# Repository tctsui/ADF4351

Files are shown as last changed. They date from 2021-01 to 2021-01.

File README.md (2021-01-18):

# ADF4351 Wideband RF Synthesizer

## Introduction
This porject is designed to incorporate Analog Devices ADF 4351 chip with Teensy 3.6. On the bottom right corner, there are two slots reserved for two different TCXO oscillators 535L250X2GT5 and XNCLH25M000THJA0P0. Only one of them should be used. The ADF4351 can be controlled using SPI by the Teensy 3.6 on-board or externally using the header pin when the Teensy is unplugged. The Teensy 3.6 is also powered by this board, so please cut the 5V pad according to https://www.pjrc.com/teensy/external_power.html  before use. The library used to control the ADF4351 chip is mostly based on the code written by David Fannin (dfannin). The register writing part of this code is adapted from the code written by Neal Pisenti (npisenti). The library is still under development, so use it with cautions.

## Hardware
### TXCO oscillators
This PCB is designed such that either 535L250X2GT5 or XNCLH25M000THJA0P0 can be used. If oscillator with frequency other than 25MHz, a corresponding modifcation to the SPI control library has to be made.
### Fast Lock Loop Filter Topology
In order to increase the lock speed, the board is modified according to page 23 in the ADF4351 manual.(a 0 Ohm on R5 and replace R4 with a 1k Ohm resistor). The SPI control library in this repository is also adapted to work under the fast lock.

### Teensy 3.6
The Teensy 3.6 is designed to be directly power by the board, so please cut the 5V pad according to https://www.pjrc.com/teensy/external_power.html  before use.

## Software
Most of code in the .cpp is based on the code written by David Fannin (dfannin). The register writing part of the code is adapted from the code written by Neal Pisenti (npisenti). 
I modidified the code to enable the fast lock functionality and calculate the different parameters required for the fast lock operation. Moreover, I added a new function FastScanSetF which only updates one register when call instead of 6. Before using FastScanSetF, FastscanabilityCheckhas to be called to set the remaining 5 registers.

## References

+ [ADF4351 Product Page](https://goo.gl/tkMjw6) Analog Devices
+ [SV1AFN ADF4351 Board](https://www.sv1afn.com/adf4351m.html) by Makis Katsouris, SV1AFN
+ [Big Number Arduino Library](https://github.com/nickgammon/BigNumber) by Nick Gammon

## Picture


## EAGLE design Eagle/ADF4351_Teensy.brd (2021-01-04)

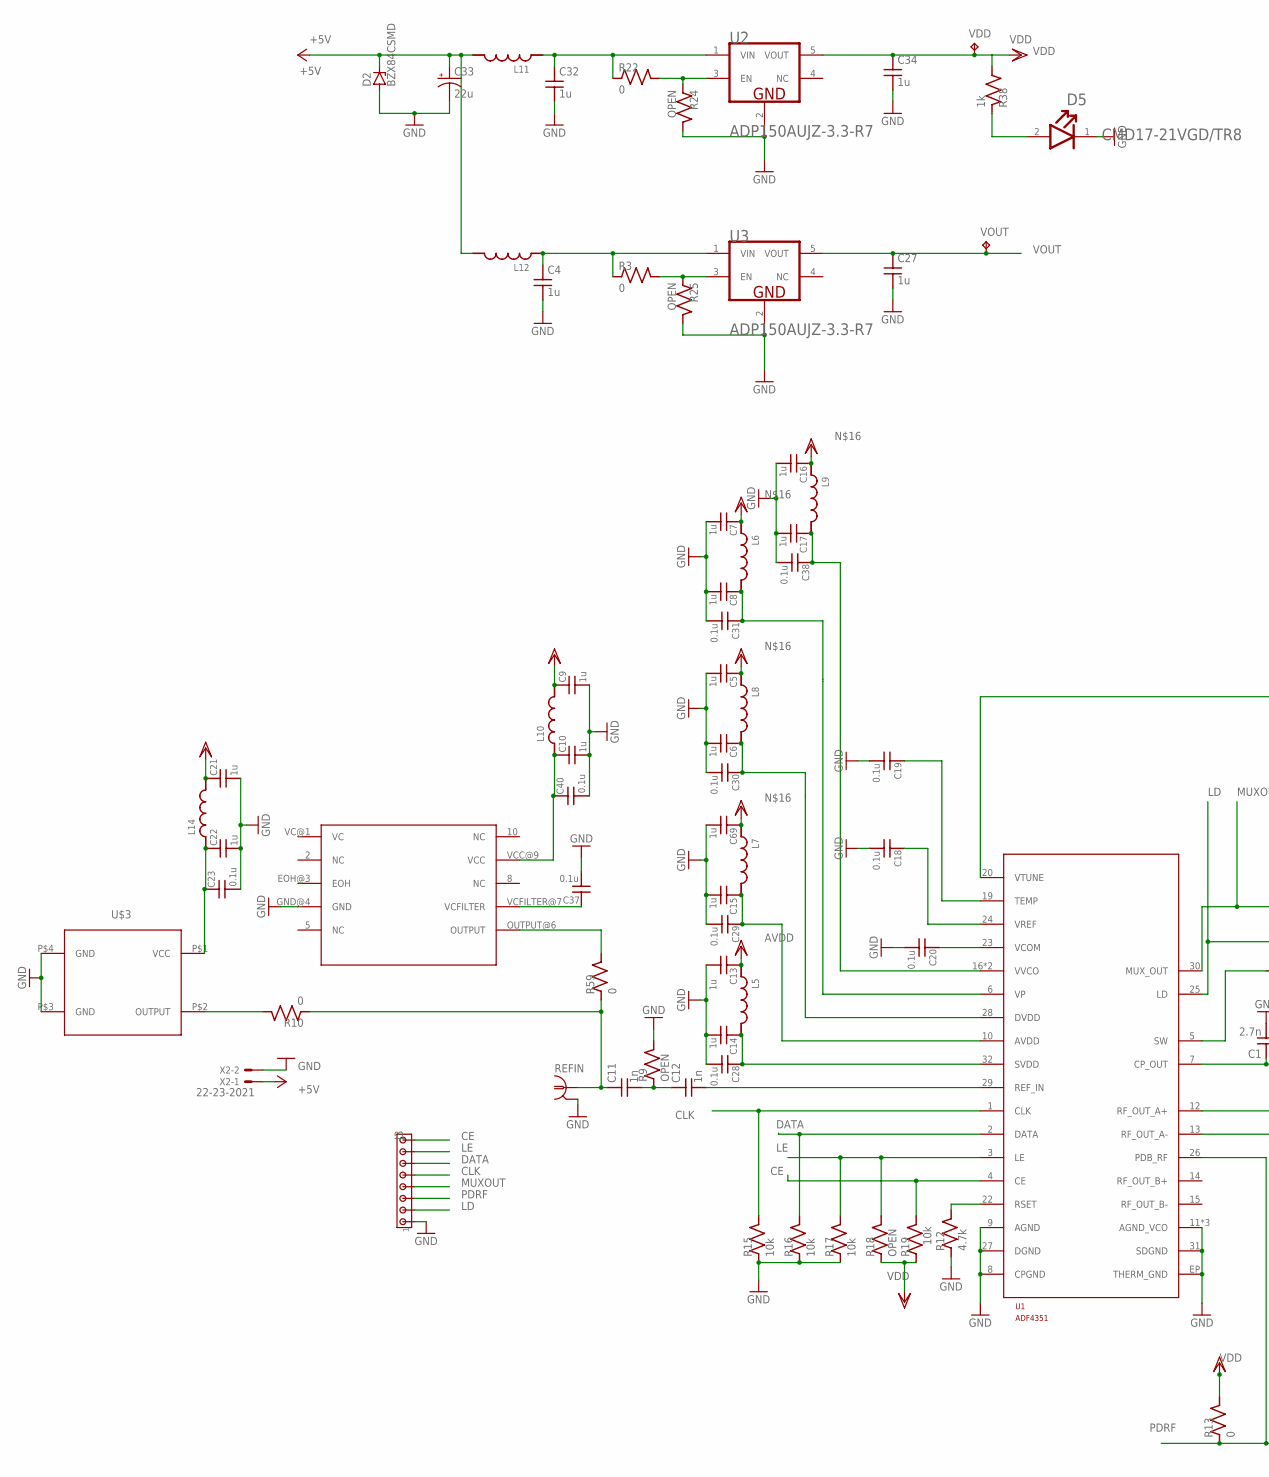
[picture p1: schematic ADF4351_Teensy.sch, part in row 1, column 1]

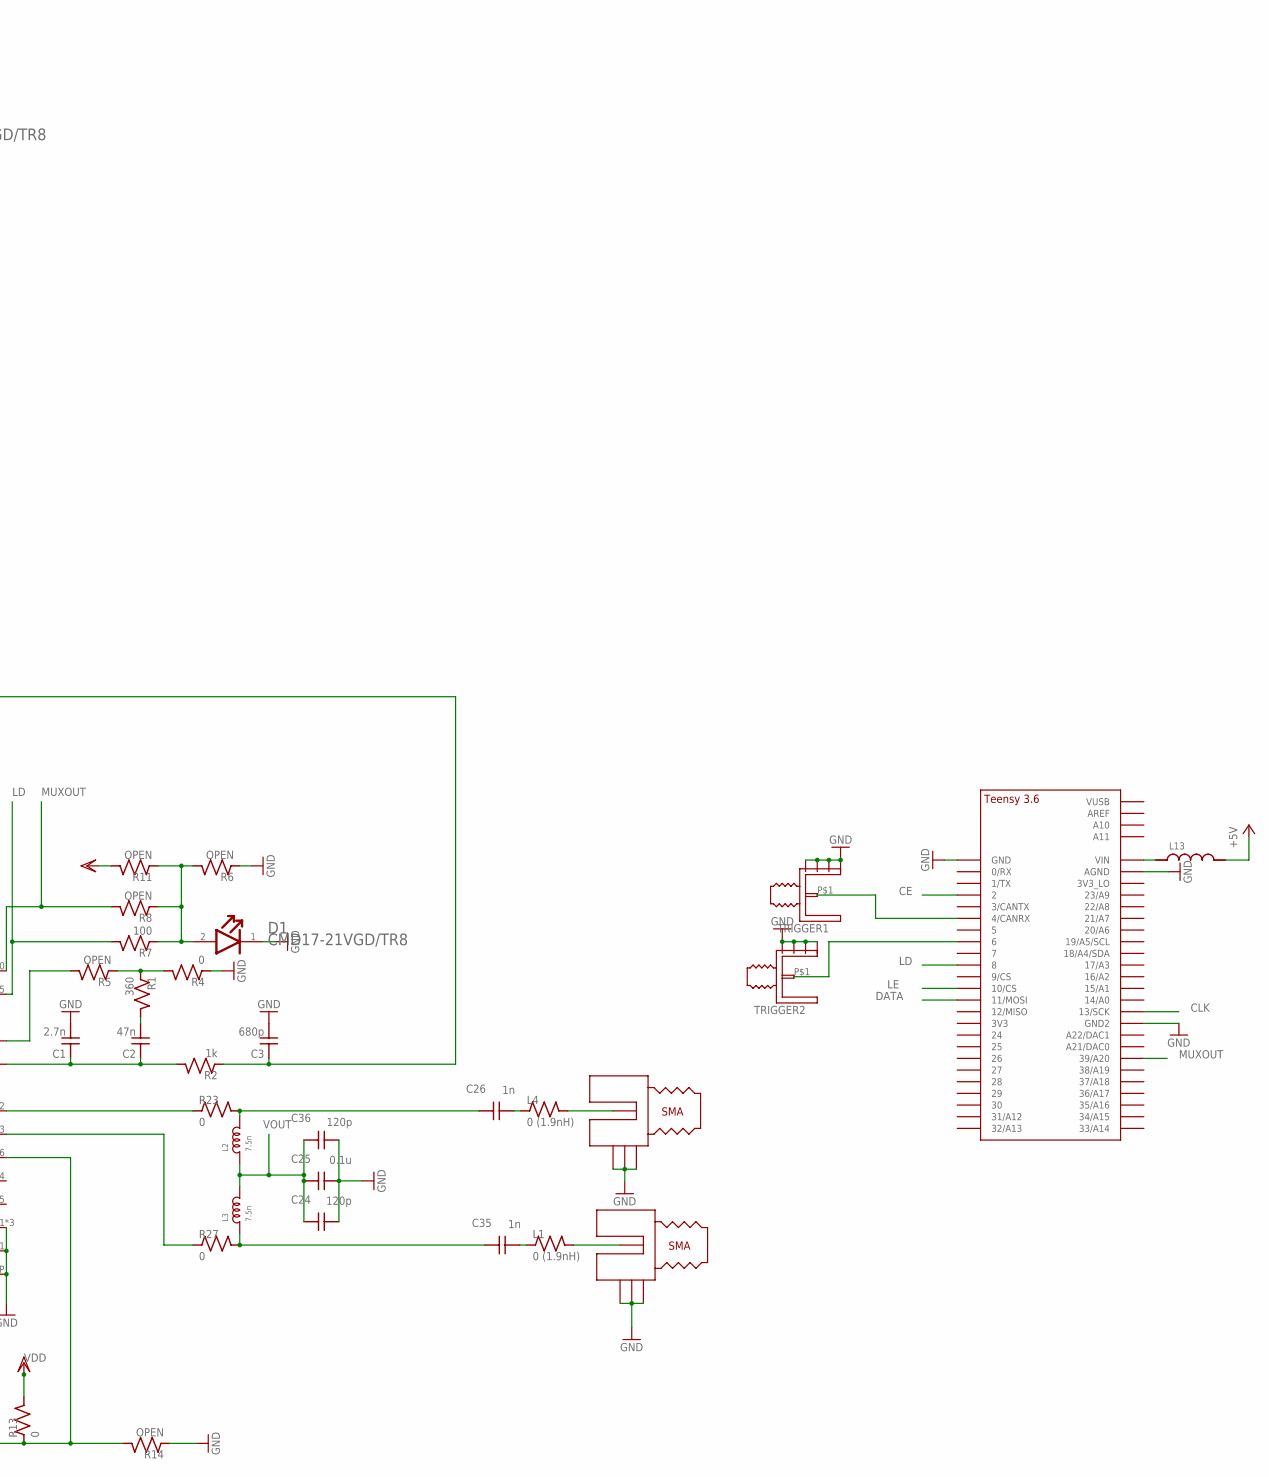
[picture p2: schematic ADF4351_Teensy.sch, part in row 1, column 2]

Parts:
535L250X2GT5: 535L250X2GT5
C1: 2.7n; C_MLCC_0603; PART_NUMBER CL10B272KB8NNNC; DIGIKEY_PART_NUMBER 1276-2022-1-ND
C2: 47n; C_MLCC_0603; PART_NUMBER CL10B473JB8NNNC; DIGIKEY_PART_NUMBER 1276-2070-1-ND
C3: 680p; C_MLCC_0603; PART_NUMBER CL10C681FB8NNNC; DIGIKEY_PART_NUMBER 1276-2327-1-ND
C4, C27, C32, C34: 1u; C_MLCC_0603; PART_NUMBER CL10B105KO8NNNC; DIGIKEY_PART_NUMBER 1276-1019-1-ND
C5, C6, C7, C8, C9, C10, C13, C14, C15, C16, C17, C21, C22, C69: 1u; C_MLCC_0306; PART_NUMBER C0816X5R1C105M050AC; DIGIKEY_PART_NUMBER 445-13750-1-ND
C11, C12: 1n; C_MLCC_0603; PART_NUMBER CL10C102JB8NNNC; DIGIKEY_PART_NUMBER 1276-1091-1-ND
C18, C19, C20, C23, C28, C29, C30, C31, C37, C38, C40: 0.1u; C_MLCC_0204; PART_NUMBER LWK105C7104MP-F; DIGIKEY_PART_NUMBER 587-5137-1-ND
C24, C36: 120p; C_MLCC_0402; PART_NUMBER UMK105CG121JVHF; DIGIKEY_PART_NUMBER 587-3738-1-ND
C25: 0.1u; C_MLCC_0402; PART_NUMBER EMK105B7104KV-F; DIGIKEY_PART_NUMBER 587-1451-1-ND
C26, C35: 1n; C_MLCC_0402; PART_NUMBER CL05C102JB5NNNC; DIGIKEY_PART_NUMBER 1276-1635-1-ND
C33: 22u; CT7343; PART_NUMBER TAJD226K020RNJ; DIGIKEY_PART_NUMBER 478-3923-1-ND
D1: VISUAL_COMMUNICATIONS_CMD17-21VGD-TR8VISUAL_COMMU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; VISUAL_COMMUNICATIONS_CMD17-21VGD-TR8_0
D2: BZX84CSMD; TO236; PART_NUMBER BZX84-C6V8,215; DIGIKEY_PART_NUMBER 1727-2942-1-ND
D5: VISUAL_COMMUNICATIONS_CMD17-21VGD-TR8VISUAL_COMMU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; VISUAL_COMMUNICATIONS_CMD17-21VGD-TR8_0; MPN CMD17-21VRD/TR8; DIGIKEY_PART_NUMBER L62501CT-ND
J1, J2: QKDLAB_JOSH_MECHANICAL_JOHNSON_SMA_18GHZ_142-0761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; QKDLAB_JOSH_MECHANICAL_JOHNSON_SMA_18GHZ_4-LAYER_142-0761-8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; PART_NUMBER 142-0761-891; DIGIKEY_PART_NUMBER J802-ND
J3: MTA08-100; 10X08MTA
L1, L4: 0 (1.9nH); R_0402; PART_NUMBER RCG04020000Z0ED; DIGIKEY_PART_NUMBER 541-1887-1-ND
L2, L3: 7.5n; 0402; PART_NUMBER 36501E7N5JTDG; DIGIKEY_PART_NUMBER A102558CT-ND
L5, L6, L7, L8, L9, L10, L11, L12, L13, L14: L_FERRITE_SMDLFERRITE_0603; L_FERRITE_0603; PART_NUMBER BLM18KG102SZ1D; DIGIKEY_PART_NUMBER 490-17350-1-ND
R1: 360; R_0603; PART_NUMBER ERJ-3GEYJ361V; DIGIKEY_PART_NUMBER P360GCT-ND
R2, R38: 1k; R_0603; PART_NUMBER ERA-3AEB102V; DIGIKEY_PART_NUMBER P1.0KDBCT-ND
R3, R4, R10, R13, R22, R59: 0; R_0603; PART_NUMBER CRCW06030000Z0EAC; DIGIKEY_PART_NUMBER 541-4012-1-ND
R5, R6, R8, R11, R14, R24, R25: OPEN; R_0603
R7: 100; R_0603; PART_NUMBER CRCW0603100RFKEAC; DIGIKEY_PART_NUMBER 541-3951-1-ND
R9, R18: OPEN; R_0603; PART_NUMBER MCT06030C1002FP500; DIGIKEY_PART_NUMBER MCT0603-10.0K-CFCT-ND
R12: 4.7k; R_0603; PART_NUMBER CRCW06034K70JNEAC; DIGIKEY_PART_NUMBER 541-3993-1-ND
R15, R16, R17, R19: 10k; R_0603; PART_NUMBER MCT06030C1002FP500; DIGIKEY_PART_NUMBER MCT0603-10.0K-CFCT-ND
R23, R27: 0; R_0402; PART_NUMBER RCG04020000Z0ED; DIGIKEY_PART_NUMBER 541-1887-1-ND
REFIN: SMA_CONNECTOR; QKDLAB_JOSH_MECHANICAL_JOHNSON_SMA_EDGE_LAUNCH_142-0701-851; PART_NUMBER 142-0701-851; DIGIKEY_PART_NUMBER J658-ND
TRIGGER1, TRIGGER2: JOHNSON_SMA_EDGE_LAUNCH_142-0701-851
U1: ADF4351
U2, U3: ANALOG_DEVICES_ADP150AUJZ-3.3-R7ANALOG_DEVICES_AD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; ANALOG_DEVICES_ADP150AUJZ-3.3-R7_2
U$1: TEENSY_3.5/3.6_BASIC
U$3: XNCLH25M000THJA0P0; PART_NUMBER_25 XNCLH25M000CHJB9P0; DIGIKEY_PART_NUMBER_25 490-XNCLH25M000CHJB9P0CT-ND
VDD: TPB1,27; B1,27
VOUT: TPB1,27; B1,27
X2: 22-23-2021

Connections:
+5V: C33.+, D2.C, L11.P$2 (2), L12.P$2 (2), L13.P$2 (2), X2.1
AVDD: C15.P$1 (1), C29.P$1 (1), L7.P$2 (2), U1.10 (AVDD)
CE: J3.8, R19.P$2 (2), U1.4 (CE), U$1.2
CLK: J3.5, R15.P$2 (2), U1.1 (CLK), U$1.13/SCK
CPOUT: C1.P$1 (1), C2.P$1 (1), R2.P$2 (2), U1.7 (CP_OUT)
DATA: J3.6, R16.P$2 (2), U1.2 (DATA), U$1.11/MOSI
DVDD: C6.P$1 (1), C30.P$1 (1), L8.P$2 (2), U1.28 (DVDD)
GND: 535L250X2GT5.GND@4 (GND), C1.P$2 (2), C3.P$2 (2), C4.P$2 (2), C5.P$2 (2), C6.P$2 (2), C7.P$2 (2), C8.P$2 (2), C9.P$2 (2), C10.P$2 (2), C13.P$2 (2), C14.P$2 (2), C15.P$2 (2), C16.P$2 (2), C17.P$2 (2), C18.P$2 (2), C19.P$2 (2), C20.P$2 (2), C21.P$2 (2), C22.P$2 (2), C23.P$2 (2), C24.P$2 (2), C25.P$2 (2), C27.P$2 (2), C28.P$2 (2), C29.P$2 (2), C30.P$2 (2), C31.P$2 (2), C32.P$2 (2), C33.-, C34.P$2 (2), C36.P$2 (2), C37.P$2 (2), C38.P$2 (2), C40.P$2 (2), C69.P$2 (2), D1.1 (CATHODE), D2.A, D5.1 (CATHODE), J1.P$2 (GND), J1.P$3 (GND), J1.P$4 (GND), J2.P$2 (GND), J2.P$3 (GND), J2.P$4 (GND), J3.1, R4.P$1 (1), R6.P$1 (1), R9.P$2 (2), R12.P$1 (1), R14.P$1 (1), R15.P$1 (1), R16.P$1 (1), R17.P$1 (1), R24.P$2 (2), R25.P$2 (2), REFIN.P$2 (2), REFIN.P$3 (2), REFIN.P$4 (2), REFIN.P$5 (2), TRIGGER1.P$2 (GND1), TRIGGER1.P$3 (GND), TRIGGER1.P$4 (GND2), TRIGGER1.P$5 (GND3), TRIGGER2.P$2 (GND1), TRIGGER2.P$3 (GND), TRIGGER2.P$4 (GND2), TRIGGER2.P$5 (GND3), U1.8 (CPGND), U1.9 (AGND), U1.11 (AGND_VCO), U1.18 (AGND_VCO), U1.21 (AGND_VCO), U1.27 (DGND), U1.31 (SDGND), U1.EP (THERM_GND), U2.2 (GND), U3.2 (GND), U$1.AGND, U$1.GND, U$1.GND2, U$3.P$3 (GND), U$3.P$4 (GND), X2.2
LD: J3.2, R7.P$2 (2), U1.25 (LD), U$1.8
LE: J3.7, R17.P$2 (2), R18.P$2 (2), U1.3 (LE), U$1.10/CS
MUXOUT: J3.4, R8.P$2 (2), U1.30 (MUX_OUT), U$1.39/A20
unnamed: C26.P$1 (1), L2.2, R23.P$2 (2)
unnamed: TRIGGER1.P$1, U$1.4/CANRX
unnamed: TRIGGER2.P$1, U$1.6
unnamed: C35.P$1 (1), L3.1, R27.P$2 (2)
unnamed: 535L250X2GT5.OUTPUT@6 (OUTPUT), R59.P$2 (2)
unnamed: C11.P$1 (1), R10.P$1 (1), R59.P$1 (1), REFIN.P$1 (1)
unnamed: 535L250X2GT5.VCC@9 (VCC), C10.P$1 (1), C40.P$1 (1), L10.P$1 (1)
unnamed: C11.P$2 (2), C12.P$1 (1), R9.P$1 (1)
unnamed: 535L250X2GT5.VCFILTER@7 (VCFILTER), C37.P$1 (1)
unnamed: D1.2 (ANODE), R6.P$2 (2), R7.P$1 (1), R8.P$1 (1), R11.P$1 (1)
unnamed: R1.P$1 (1), R4.P$2 (2), R5.P$1 (1)
unnamed: C2.P$2 (2), R1.P$2 (2)
unnamed: C4.P$1 (1), L12.P$1 (1), R3.P$1 (1), U3.1 (VIN)
unnamed: L13.P$1 (1), U$1.VIN
unnamed: C26.P$2 (2), L4.P$1 (1)
unnamed: C35.P$2 (2), L1.P$1 (1)
unnamed: J1.P$1 (SIG), L4.P$2 (2)
unnamed: J2.P$1 (SIG), L1.P$2 (2)
unnamed: R3.P$2 (2), R25.P$1 (1), U3.3 (EN)
unnamed: R22.P$2 (2), R24.P$1 (1), U2.3 (EN)
unnamed: C18.P$1 (1), U1.24 (VREF)
unnamed: R10.P$2 (2), U$3.P$2 (OUTPUT)
unnamed: C32.P$1 (1), L11.P$1 (1), R22.P$1 (1), U2.1 (VIN)
unnamed: D5.2 (ANODE), R38.P$1 (1)
unnamed: C22.P$1 (1), C23.P$1 (1), L14.P$1 (1), U$3.P$1 (VCC)
PDRF: J3.3, R13.P$1 (1), R14.P$2 (2), U1.26 (PDB_RF)
REFIN: C12.P$2 (2), U1.29 (REF_IN)
RFOUTAM: R27.P$1 (1), U1.13 (RF_OUT_A-)
RFOUTAP: R23.P$1 (1), U1.12 (RF_OUT_A+)
RSET: R12.P$2 (2), U1.22 (RSET)
SVDD: C14.P$1 (1), C28.P$1 (1), L5.P$2 (2), U1.32 (SVDD)
SW: R5.P$2 (2), U1.5 (SW)
TEMP: C19.P$1 (1), U1.19 (TEMP)
VCO: C17.P$1 (1), C38.P$1 (1), L9.P$2 (2), U1.16 (VVCO), U1.17 (VVCO)
VCOM: C20.P$1 (1), U1.23 (VCOM)
VDD: C5.P$1 (1), C7.P$1 (1), C9.P$1 (1), C13.P$1 (1), C16.P$1 (1), C21.P$1 (1), C34.P$1 (1), C69.P$1 (1), L5.P$1 (1), L6.P$1 (1), L7.P$1 (1), L8.P$1 (1), L9.P$1 (1), L10.P$2 (2), L14.P$2 (2), R11.P$2 (2), R13.P$2 (2), R18.P$1 (1), R19.P$1 (1), R38.P$2 (2), U2.5 (VOUT), VDD.TP
VOUT: C24.P$1 (1), C25.P$1 (1), C27.P$1 (1), C36.P$1 (1), L2.1, L3.2, U3.5 (VOUT), VOUT.TP
VP: C8.P$1 (1), C31.P$1 (1), L6.P$2 (2), U1.6 (VP)
VTUNE: C3.P$1 (1), R2.P$1 (1), U1.20 (VTUNE)

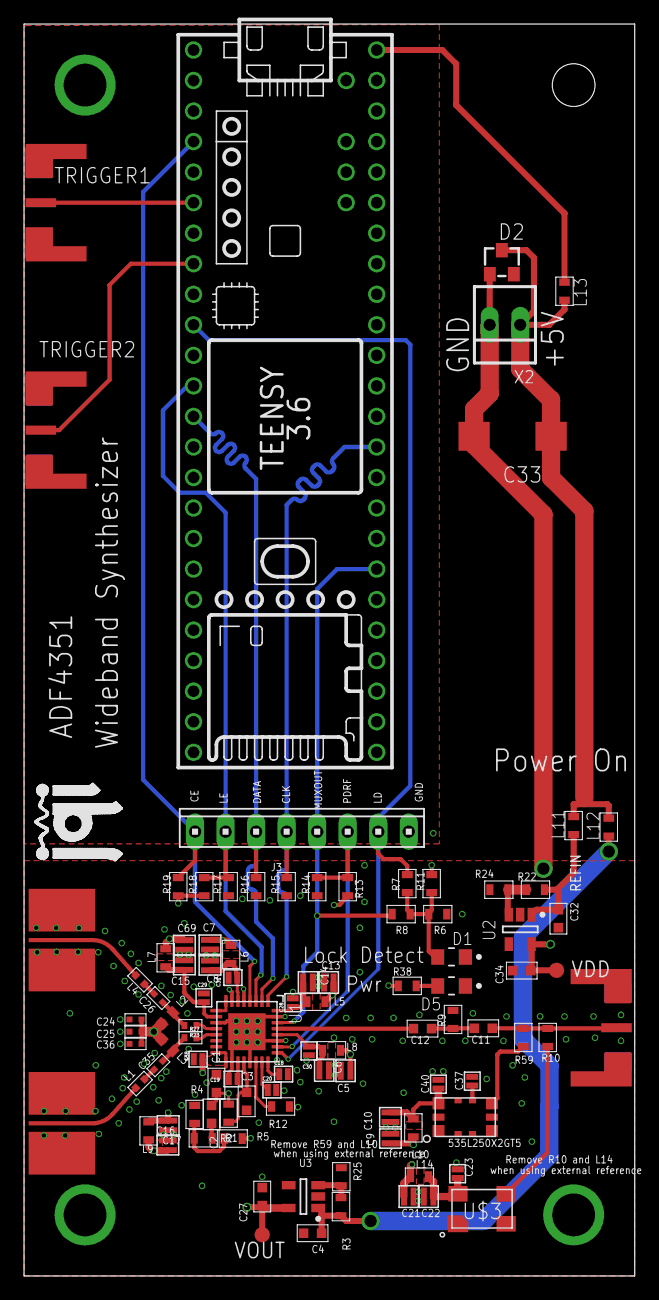
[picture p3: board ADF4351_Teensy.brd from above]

Board: 4 copper layers, 50.8 x 104.1 mm, 99 parts (0 on the bottom side), 50 nets.

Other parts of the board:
U$2: JQI_LOGO_POSITIVE-SILKSCREEN

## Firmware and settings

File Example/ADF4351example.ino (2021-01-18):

/*!
   ADF4351 example program
*/

#include <Arduino.h>
#include "ADF4351.h"

#define SWVERSION "1.0"

#define PIN_SS 10  ///< SPI slave select pin, default value

int triggerIn = 0 ;
int ReverseScanDir=0;
unsigned long StartFrequency = 1500000000UL;
unsigned long StopFrequency = 1500000000UL;//StopFrequency needs to be larger than the StartFrequency,since unsigned long is used.
unsigned long FrequencyScanStep = 10;
unsigned long FrequencyScanCounter = 0 ;
volatile unsigned long FrequncyRequested = StartFrequency;
ADF4351  vfo(PIN_SS, SPI_MODE0, 300000UL , MSBFIRST) ;


void setup()
{
  Serial.begin(115200) ;
  Serial.print("Hello adf4351 demo v") ;
  Serial.println(SWVERSION) ;
  Wire.begin() ;
  
  /*!
     setup the chip (for a 10 mhz ref freq)
     most of these are defaults
  */
  vfo.pwrlevel = 0 ; ///< sets to -4 dBm output
  vfo.RD2refdouble = 0 ; ///< ref doubler off
  vfo.RD1Rdiv2 = 0 ;   ///< ref divider off
  vfo.ClkDiv = 150 ;
  vfo.BandSelClock = 200 ;
  vfo.RCounter = 1 ;  ///< R counter to 1 (no division)
  vfo.ChanStep = 10000 ;  ///< set to 10 kHz steps


  /*!
     sets the reference frequency to 25 Mhz
  */
  delay(500);
  if ( vfo.setrf(25000000UL) ==  0 )
    Serial.println("ref freq set to 25 Mhz") ;
    else
      Serial.println("ref freq set error") ;
      /*!
         initialize the chip
      */
      
      vfo.init() ;

  /*!
     enable frequency output
  */
  vfo.enable() ;


vfo.setf(StartFrequency);
/*
Because FastScanSetF only update one of the register when the frequency is changed, so FastscanabilityCheck needs to be run to set the remaining 5 registers.
*/

//vfo.FastscanabilityCheck(StartFrequency,StopFrequency,FrequencyScanStep);


}



void loop()
{
//vfo.setf(StartFrequency);
    Serial.println("Freq requested");
    Serial.println(StartFrequency);
    Serial.println("RD1Rdiv2");
    Serial.println(vfo.RD1Rdiv2);
    Serial.println("BandSelClock");
    Serial.println(vfo.BandSelClock);
    Serial.println(" ClkDiv");
    Serial.println(vfo.ClkDiv);
    Serial.println("PFD");
    Serial.println(vfo.PFDFreq);
    Serial.println("RCounter");
    Serial.println(vfo.RCounter);
    Serial.println("Output divider");
    Serial.println(vfo.outdiv);
    Serial.println("Frac");
    Serial.println(vfo.Frac) ;
    Serial.println("Mod");
    Serial.println(vfo.Mod) ;
    Serial.println("Int");
    Serial.println(vfo.N_Int);
    Serial.println("cfrequency");
    Serial.println(vfo.cfreq);
    Serial.println("Output frequency");
    Serial.println(vfo.PFDFreq*(vfo.N_Int+((float)vfo.Frac)/((float)vfo.Mod))/vfo.outdiv);
delay(10000);
//
//if(FrequencyScanCounter <= FrequencyScanStep){
// FrequncyRequested = StartFrequency + (unsigned long)(FrequencyScanCounter*(StopFrequency-StartFrequency)/FrequencyScanStep);
//
//  unsigned long StartTime = micros();
//  //vfo.setf(FrequncyRequested);
//  vfo.FastScanSetF(FrequncyRequested);
//  unsigned long ElapsedTime =  micros()-StartTime;
//  Serial.println("Computing Time us");
//  Serial.println(ElapsedTime);
//  if(ReverseScanDir==0)
//    FrequencyScanCounter = FrequencyScanCounter + 1;
//  else
//    FrequencyScanCounter = FrequencyScanCounter - 1;
//    
//  if(FrequencyScanCounter ==FrequencyScanStep) 
//  ReverseScanDir=1;
//  else if (FrequencyScanCounter ==0)
//  ReverseScanDir=0;
//
//  }
//  Serial.println("Frac");
// Serial.println(vfo.Frac) ;
//delay(1000);
//delayMicroseconds(1000);
 
  
}

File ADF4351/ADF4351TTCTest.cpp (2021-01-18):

/*
ADF4351.cpp -ADF4351 PLL communication library

Most of this code is based on the code written by David Fannin (dfannin).
The register writing part of this code is adapted from the code written by Neal Pisenti (npisenti)

I have added two functions FastscanabilityCheck and FastScanSetF. Instead of updating all the 6 registers, FastScanSetF only update the register 0 when called, thus saving some computation time.
FastscanabilityCheck makes sure the other 5 registers remain the same during the frequency scan.


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
*/

#include "ADF4351.h"

uint32_t steps[] = { 1000, 5000, 10000, 50000, 100000 , 500000, 1000000 }; ///< Array of Allowed Step Values (Hz)




// ADF4351 settings


ADF4351::ADF4351(byte pin, uint8_t mode, unsigned long  speed, uint8_t order )
{
  spi_settings = SPISettings(speed, order, mode) ;
  pinSS = pin ;
  // settings for 100 mhz internal
  reffreq = REF_FREQ_DEFAULT ;
  enabled = false ;
  cfreq = 0 ;
  ChanStep = steps[2] ;
  RD2refdouble = 0 ;
  RCounter = 1 ;
  RD1Rdiv2 = 0 ;
  BandSelClock = 200 ;
  ClkDiv = 80 ;
  Prescaler = 1 ;
  pwrlevel = 0 ;
  PowerDown = 0;
}

void ADF4351::init()
{
  pinMode(pinSS, OUTPUT) ;
  digitalWrite(pinSS, LOW) ;
  pinMode(PIN_CE, OUTPUT) ;
  pinMode(PIN_LD, INPUT) ;
  SPI.begin();
} ;

int ADF4351::FastscanabilityCheck(uint32_t StartF, uint32_t StopF,uint32_t ScanStep)
{
	if(StartF > ADF_FREQ_MAX || StopF > ADF_FREQ_MAX || StartF < ADF_FREQ_MIN || StopF < ADF_FREQ_MIN) {
	  Serial.println("The upper or lower bound is outside the frequency range. The maximum frequency is 4294967295");
	  return 1;
	}
	
	int LocalOscRStart =   2200000000UL / StartF;
	int LocalOscRStop =   2200000000UL / StopF ;
	
	if (LocalOscRStart != LocalOscRStop ) {
	  Serial.println("Scan range too large. Only Register 0 should be updated in this mode. Current scan range requires updating other registers as well. ");
	  return 1;
	}
	if ( abs(StartF-StopF)/ScanStep<ChanStep) {
	  Serial.println(F("ScanStep too large. The ScanStep being used is larger than the step size being used. "));
	  return 1;
	}
	
	outdiv = 1 ;
	RfDivSel = 0 ;

  // select the output divider
	while (  outdiv <=  LocalOscRStart   && outdiv <= 64 ) {
      outdiv *= 2 ;
      RfDivSel++  ;
	}
  
	if(StartF> 3600000000UL )
      Prescaler = 1 ;
	else
      Prescaler = 0 ; 

	RD1Rdiv2 = 1;// 1 is needed for Fast Lock to ensure 50% duty cycle
	
  PFDFreq = (float) reffreq  * ( (float) ( 1.0 + RD2refdouble) / (float) (RCounter * (1.0 + RD1Rdiv2)));  // find the loop freq
  BigNumber::begin(10) ;
  char tmpstr[20] ;
  // kludge - BigNumber doesn't like leading spaces
  // so you need to make sure the string passed doesnt
  // have leading spaces.
  int cntdigits = 0 ;
  uint32_t num = (uint32_t) ( PFDFreq / 10000 ) ;

  while ( num != 0 )  {
    cntdigits++ ;
    num /= 10 ;
  }

  dtostrf(PFDFreq, cntdigits + 8 , 3, tmpstr) ;
  // end of kludge
  BigNumber BN_PFDFreq = BigNumber(tmpstr) ;
  
  BigNumber BN_N = ( BigNumber(StartF) * BigNumber(outdiv) ) /BN_PFDFreq ;
  N_Int =  (uint16_t) ( (uint32_t)  BN_N ) ;
  BigNumber BN_Mod = BigNumber(((uint32_t)PFDFreq)) / (BigNumber(ChanStep)* BigNumber(outdiv)) ;
  Mod =((uint32_t) BN_Mod) ;
  

  if (Mod>=4095)
  {
	  uint32_t RCheck =ceil((float) reffreq  * ( (float) ( 1.0 + RD2refdouble) / (float) (4094*ChanStep* (1.0 + RD1Rdiv2)*outdiv)));
	/*
	  When the Mod is larger than the upper bound for the current choice of R, we can overcome this issue by using a larger R.
	*/
	  if(RCheck <1023)
	  {
		  if(RCheck %2==0)
		  {
			  RCounter=RCheck ;
		  }
		  else
		  {
			  RCounter=RCheck + 1;
		  }
		  PFDFreq =(float) reffreq  * ( (float) ( 1.0 + RD2refdouble) / (float) (RCounter * (1.0 + RD1Rdiv2))); 
		  cntdigits = 0 ;
		  num = (uint32_t) ( PFDFreq / 10000 ) ;

		  while ( num != 0 )  {
          cntdigits++ ;
          num /= 10 ;
          }
		  dtostrf(PFDFreq, cntdigits + 8 , 3, tmpstr) ;
		  BN_PFDFreq = BigNumber(tmpstr) ;
		  BN_N = ( BigNumber(StartF) * BigNumber(outdiv) ) / BN_PFDFreq ;
		  N_Int =  (uint16_t) ( (uint32_t)  BN_N ) ;
		  BN_Mod = BN_PFDFreq / (BigNumber(ChanStep)* BigNumber(outdiv)) ;
		  Mod = ((uint32_t) BN_Mod);

	  }
		else 
		{
		Serial.println(F("Change step size too small")) ;
		return 1;
		}
	  
  } 
    BigNumber BN_Diff= BigNumber(StartF)* BigNumber(outdiv)-BigNumber(N_Int)*BN_PFDFreq;


	BigNumber BN_Frac = BN_Diff * BN_Mod/ BN_PFDFreq;
	
	
 	if(((uint32_t)PFDFreq)/5000000UL==0)
		BandSelClock=1;
	else{
		BandSelClock=((uint32_t)(PFDFreq/((float)5000000))) + 1; 
		if(BandSelClock > 255)	BandSelClock=255;
	}
	
	/*
	The BandSelClock divider should be set to a value such that PFDFreq/BandSelClock is smaller than 500kHz (DBit23 in Register 3 is set to 1)
	,125kHz (DBit23 in Register 3 is set to 0)
	*/
	
	ClkDiv = (int)(((10+(20e-6)*PFDFreq)/Mod) + 1);
	/*
    The value of ClkDiv determines the duration of wide bandiwdth mode used in fast lock mode. 10 cycles of PFDFreq of band selection of VCO and 20 us for PLL in wide bandwidth mode.
    */
	
	Frac =((uint32_t) BN_Frac);
	if ( Mod < 2 || Mod > 4095) {
    Serial.println(F("Mod out of range")) ;
    return 1 ;
  }

  if ( (uint32_t) Frac > (Mod - 1) ) {
    Serial.println(F("Frac out of range")) ;
    return 1 ;
  }

  if ( Prescaler == 0 && ( N_Int < 23  || N_Int > 65535)) {
    Serial.println(F("N_Int out of range")) ;
    return 1;

  } else if ( Prescaler == 1 && ( N_Int < 75 || N_Int > 65535 )) {
    Serial.println(F("N_Int out of range")) ;
    return 1;
  }

  // setting the registers to default values
 


	ADF4351::setR5();
	ADF4351::setR4();
	ADF4351::setR3FastScan();
	ADF4351::setR2FastScan();
	ADF4351::setR1();
  	ADF4351::setR0();

	ADF4351::writeRegister(_r5);

	ADF4351::writeRegister(_r4);

	ADF4351::writeRegister(_r3);

	ADF4351::writeRegister(_r2);

	ADF4351::writeRegister(_r1);

	ADF4351::writeRegister(_r0); 
	
	



  return 0 ;  // ok
}

int ADF4351::FastScanSetF(uint32_t freq){

 	BigNumber::begin(10) ;  
	BigNumber BN_N = ( BigNumber(freq) * BigNumber(outdiv) ) /BigNumber(((uint32_t)PFDFreq)) ;
	N_Int =  (uint16_t) ( (uint32_t)  BN_N ) ;
	BigNumber BN_Diff= BigNumber(freq)* BigNumber(outdiv)-BigNumber(N_Int)*BigNumber(((uint32_t)PFDFreq));
	Frac = (uint32_t) ((((float)((uint32_t)BN_Diff) )/ PFDFreq)*Mod + 0.5);
	/*
	I try to avoid using BigNumber in this funcitn to reduce the computation time.
	*/
	ADF4351::setR0();
	ADF4351::writeRegister(_r0); 
	BigNumber::finish() ;
	
	return 0;
	
}
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

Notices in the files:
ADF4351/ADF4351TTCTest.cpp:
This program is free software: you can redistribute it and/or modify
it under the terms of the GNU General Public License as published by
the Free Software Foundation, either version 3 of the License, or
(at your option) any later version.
